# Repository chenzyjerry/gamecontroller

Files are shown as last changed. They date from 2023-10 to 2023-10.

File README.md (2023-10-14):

# gamecontroller

This is a game controller built during Hack the Valley 8 as part of [the game we built](https://github.com/fiona-cai/HTV2023). It uses an Arduino UNO (and UNO Prototype Shield), joystick, and two tactile pushbuttons. This results in a joystick input, the joystick switch, and the two pushbuttons as possible inputs.

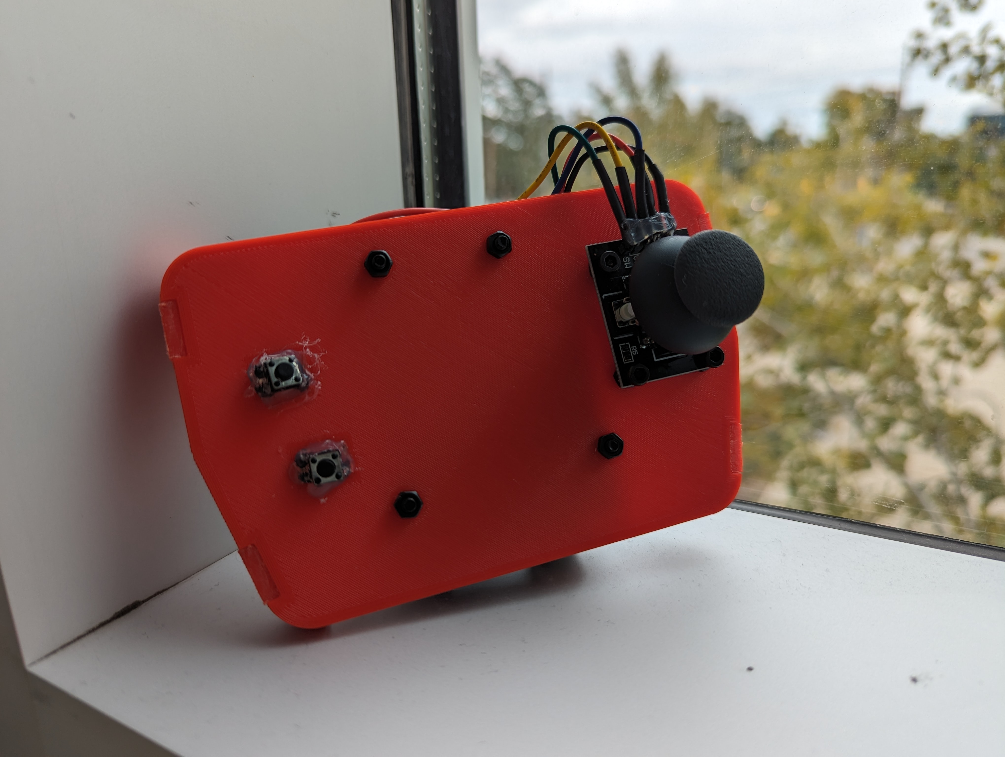
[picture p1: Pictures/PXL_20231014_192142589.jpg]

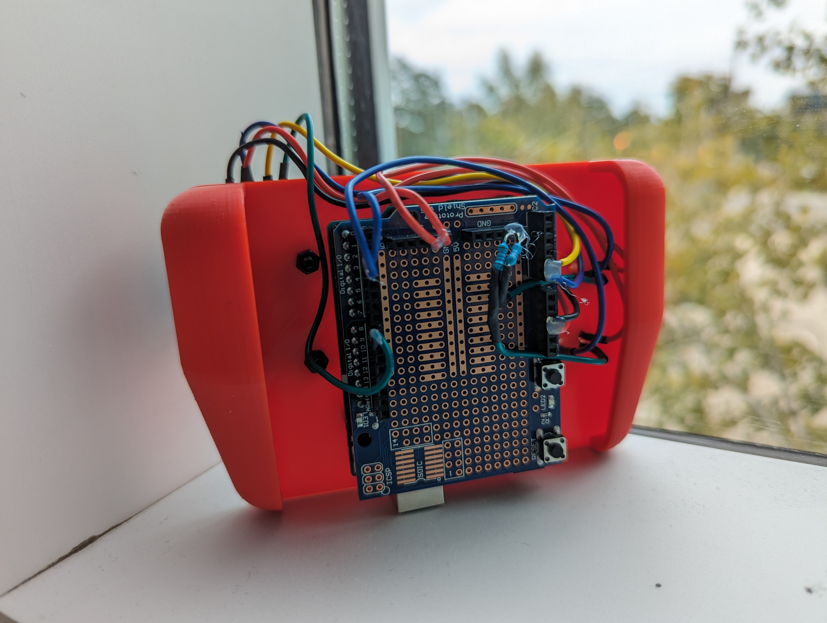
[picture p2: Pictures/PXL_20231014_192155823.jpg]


The shell was designed in SolidWorks and 3D printed in AMZ3D red PLA on an Ender 3 V2. An exposed-back design was chosen due to the ease of making modifications. The UNO and joystick module were mounted using M3x16mm bolts and nuts. The mounts for the pushbuttons were drilled out due to insufficient clearances and the locking tabs were filed down to fit. The pushbuttons use a mix of available pull-down resistors (10k and 5.1k ohm). All connections were soldered, wrapped in heatshrink, and secured in place with hot glue.

Unlike the Arduino Pro Micro or Leonardo, UNO cannot function as an HID without the use of firmware hacks like ([UnoJoy](https://github.com/AlanChatham/UnoJoy/tree/master)). However, the need to flash back and forth between Arduino and joystick modes each time any modifications needed to be made was deemed to be too inconvenient. Instead, I selected the approach of reading the Arduino's serial output and converting it into keyboard commands using PyAutoGUI.

Great thanks to [prabeenraj01](https://www.instructables.com/Joystick-Controlled-PC-Mouse-Using-Arduino-UNO/), who's code served as the basis for the firmware of this project.

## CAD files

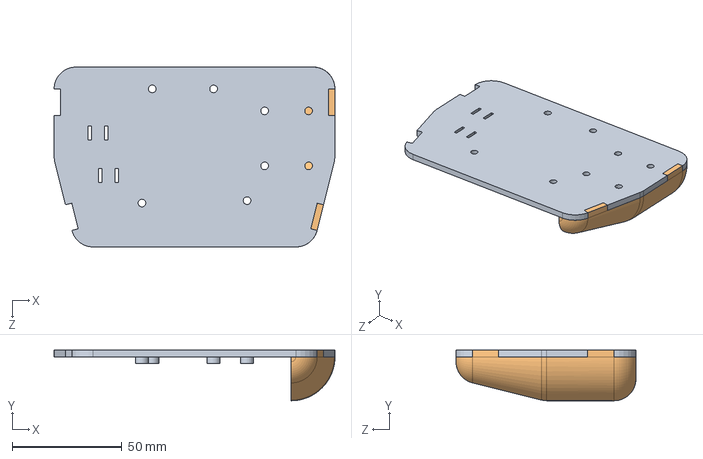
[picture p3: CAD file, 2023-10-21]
controller_cad_files/controller.SLDASM
127.8 x 23.0 x 81.9 mm
controllerplate
controllerhandle

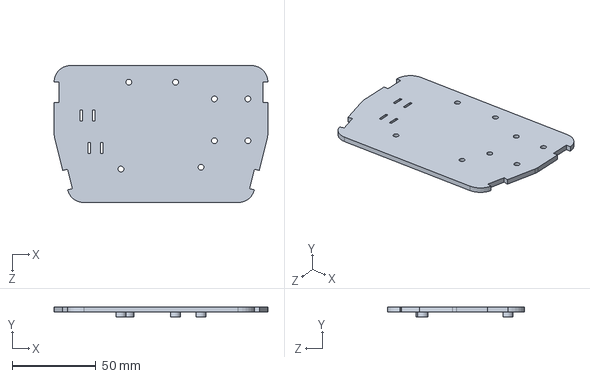
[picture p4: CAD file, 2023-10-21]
controller_cad_files/controllerplate.SLDPRT
127.8 x 6.00 x 81.9 mm

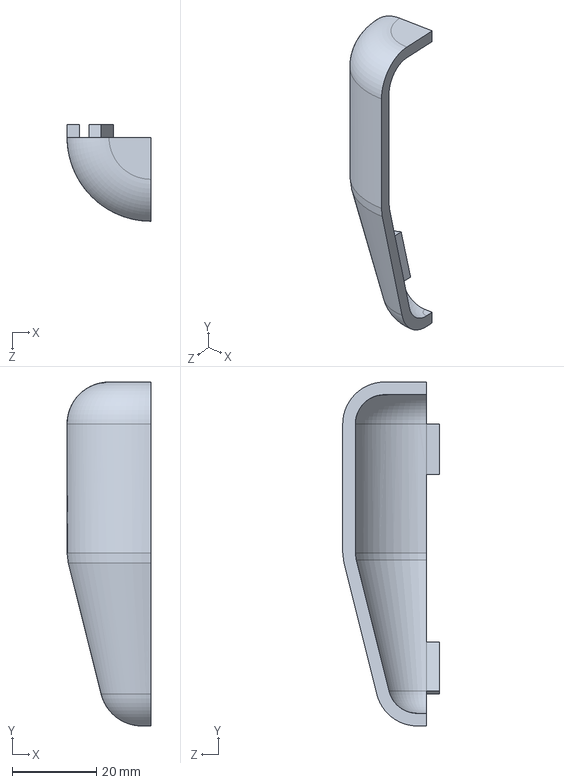
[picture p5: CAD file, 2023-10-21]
controller_cad_files/controllerhandle.SLDPRT
20.0 x 81.9 x 23.0 mm

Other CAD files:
controller_cad_files/controllerhandle.STL
controller_cad_files/controllerplate.STL

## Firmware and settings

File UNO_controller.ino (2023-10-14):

int B1_pin = 2; //set digital pin for top button
int B2_pin = 3; //set digital pin for bottom button
int SW_pin = 8; //set digital pin for joystick button

void setup() { //set pin mode for all buttons
 pinMode(B1_pin,INPUT_PULLUP);
 pinMode(B2_pin,INPUT_PULLUP);
 pinMode(SW_pin,INPUT_PULLUP);
 
Serial.begin(9600);
}

void loop() {
  int X = analogRead(A1); //read X and Y values for joystick axes
  int Y = analogRead(A0);
  int x = map(X, 1, 1023, 1917, 2);
  int y = map(Y, 1, 1023, 2, 1077);
  
if(digitalRead(B1_pin)==LOW){
Serial.print("a"); //prints 'a' if top button is not pressed

}else{
  Serial.print("b"); //prints 'b' if top button is pressed
}

Serial.print(" ");
if(digitalRead(B2_pin)==LOW){
Serial.print("e"); //prints 'e' if top button is not pressed

}else{
  Serial.print("f"); //prints 'f' if top button is pressed
}

Serial.print(" ");
if(digitalRead(SW_pin)==LOW){
Serial.print("c"); //prints 'c' if top button is not pressed

}else{
  Serial.print("z"); //prints 'z' if top button is pressed
}

Serial.print(" ");
Serial.print(x); //print joystick X axis value
Serial.print(" ");
Serial.print(y); //print joystick Y axis value
Serial.print(" ");
Serial.println("m");
delay(180);
}

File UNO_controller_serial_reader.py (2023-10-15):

import serial
import pyautogui as pg
import os
import platform


pg.FAILSAFE=False

# be lazy
if platform.system() == 'Windows':
    ser = serial.Serial("COM3",'9600')
elif platform.system() == 'Darwin':
    ser = serial.Serial("/dev/cu.usbmodem212101",'9600')
elif platform.system() == 'Linux':
    ser = serial.Serial("/dev/ttyACM0",'9600')

leftDown = False
rightDown = False
while 1:
    read = ser.readline().decode('ascii')
    readArray = read.split()
    b = readArray[0]
    f = readArray[1]
    c = readArray[2]
    x = readArray[3]
    y = readArray[4]
    m = readArray[5]
    print(b, ' ', f, ' ', c, ' ', x,' ',y,' ',m)
    if c=='c':
        pg.click(button='left')
    if b=='b':
        pg.press('b')
    if f=='f':
        pg.press('f')
    if int(x) < 900:
        pg.keyDown('left')
        leftDown = True
    elif leftDown:
        pg.keyUp('left')
        leftDown = False
    if int(x) > 1000:
        pg.keyDown('right')
        rightDown = True
    elif rightDown:
        pg.keyUp('right')
        rightDown = False

    if int(y) < 400:
        pg.press('up')

    # pg.moveTo(int(x), int(y))

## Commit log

2023-10-14 Update and rename Arduino_UNO_Mouse.ino to UNO_controller.ino
2023-10-14 Update and rename arduino mouse.py to UNO_controller_serial_reader.py
2023-10-14 Controller CAD Files
    [controllerhandle.STL, controllerplate.STL]
2023-10-21 Added complete SolidWorks CAD files
    [controller.SLDASM, controllerhandle.SLDPRT, controllerhandle.STL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]
